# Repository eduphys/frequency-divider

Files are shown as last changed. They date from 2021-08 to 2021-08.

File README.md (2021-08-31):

# README

This repository contains the schematics and firmware for a frequency divider used in an experiment for time resolved transmission electron microscopy.
The frequency divider can operate up to 4 GHz and is optimized for low timing jitter. The jitter has not been determined by measurements, but calculations using the jiter of the individual components of the signal path lead to <5ps. The input is designed for 90-200mV pp.

The divider can be configured for a division factor of (2^a)(2^b) with a=0...3 and b=0...5.

## CAUTION:
The NB6N239S chip is not manufactured anymore. It is highly recommended to re-design the board!

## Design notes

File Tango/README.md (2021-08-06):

# README

This Tango server connectos th the Frequency divider.
The frequency divider is connected via an USB cable to the computer.
The software on the divider recieves the divider setting over the serial protocol

## Setup

### Permission
In order to be able to connect to the serial port, the linux user needs the permissions

  sudo usermod -a -G dialout $USER

Log out and log in again

Find the serial port, best with 

  dmesg | grep tty

### Packages

The python programm nees the pyserial libraries

## Debug

## Serial GUI
To debug the serial connection, one can use the programm cutecom.

## Permission denied
You could try

   sudo chmod 666 /dev/ttyACM0

Which will give you read/write permissions for the serial port (thanks to https://discourse.nodered.org/t/serial-port-issue-permission-denied-cannot-open-dev-ttyacm0/4500/2)

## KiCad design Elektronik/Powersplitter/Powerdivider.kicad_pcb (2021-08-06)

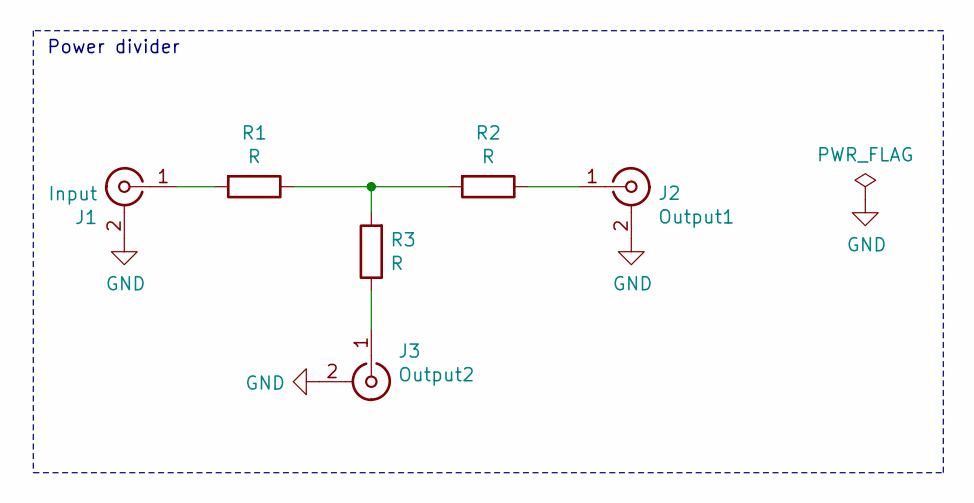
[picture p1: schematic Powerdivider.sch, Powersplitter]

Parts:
J1: Input; SMA_Amphenol_132289_EdgeMount
J2: Output1; SMA_Amphenol_132289_EdgeMount
J3: Output2; SMA_Amphenol_132289_EdgeMount
R1, R2, R3: R; R_0603_1608Metric_Pad1.05x0.95mm_HandSolder

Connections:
GND: J1.2 (Ext), J2.2 (Ext), J3.2 (Ext)
unnamed: J1.1 (In), R1.2
unnamed: J2.1 (In), R2.1
unnamed: J3.1 (In), R3.1
unnamed: R1.1, R2.2, R3.2

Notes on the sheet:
Power divider

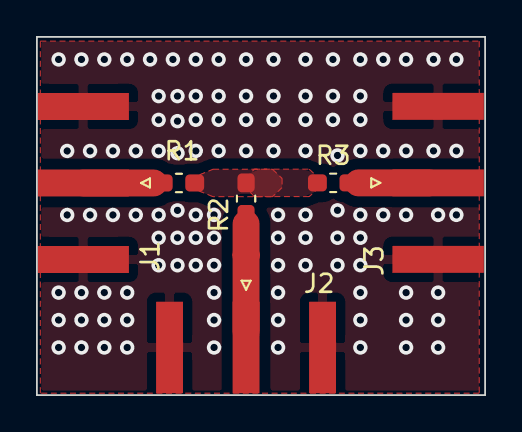
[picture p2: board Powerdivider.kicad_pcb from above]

Board: 2 copper layers, 24.9 x 19.9 mm, 6 parts (0 on the bottom side), 5 nets.

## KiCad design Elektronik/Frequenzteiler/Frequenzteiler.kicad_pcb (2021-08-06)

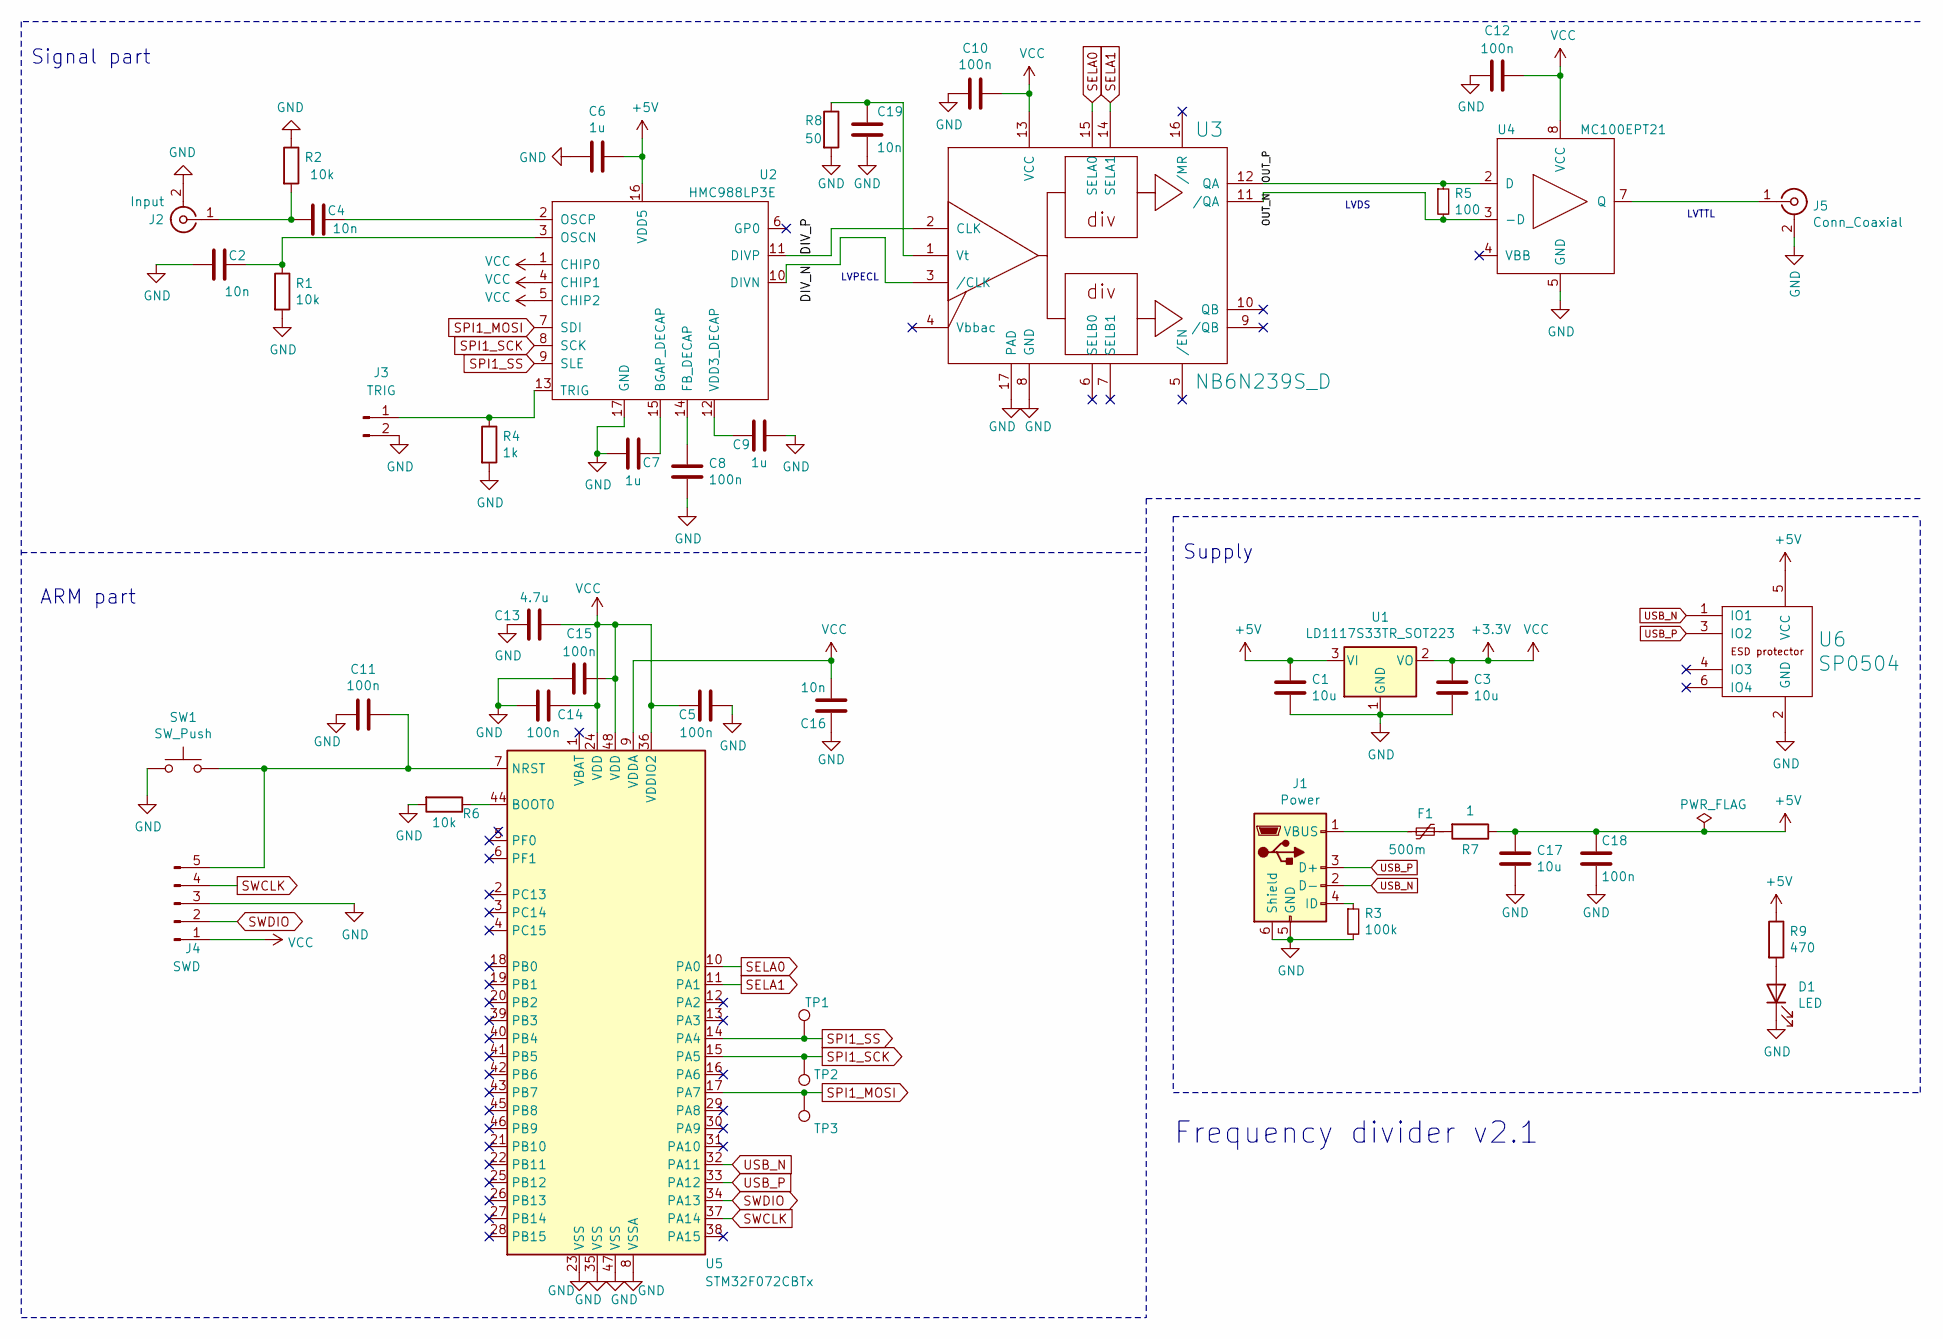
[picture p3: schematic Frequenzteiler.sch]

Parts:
C1, C3, C17: 10u; C_1206_3216Metric_Pad1.42x1.75mm_HandSolder
C2, C4, C16, C19: 10n; C_0603_1608Metric_Pad1.05x0.95mm_HandSolder
C5, C8, C10, C11, C12, C14, C15, C18: 100n; C_0603_1608Metric_Pad1.05x0.95mm_HandSolder
C6, C7, C9: 1u; C_0603_1608Metric_Pad1.05x0.95mm_HandSolder
C13: 4.7u; C_0805_2012Metric_Pad1.15x1.40mm_HandSolder
D1: LED; LED_0805_2012Metric_Pad1.15x1.40mm_HandSolder
F1: 500m; R_1206_3216Metric_Pad1.42x1.75mm_HandSolder
J1: Power; USB_Mini-B_Lumberg_2486_01_Horizontal
J2: Input; SMA_Amphenol_132289_EdgeMount
J3: TRIG; PinHeader_1x02_P2.54mm_Vertical
J4: SWD; PinHeader_1x05_P2.54mm_Vertical
J5: Conn_Coaxial; SMA_Amphenol_132289_EdgeMount
R1, R2, R6: 10k; R_0603_1608Metric_Pad1.05x0.95mm_HandSolder
R3: 100k; R_0603_1608Metric_Pad1.05x0.95mm_HandSolder
R4: 1k; R_0603_1608Metric_Pad1.05x0.95mm_HandSolder
R5: 100; R_0603_1608Metric_Pad1.05x0.95mm_HandSolder
R7: 1; R_0603_1608Metric_Pad1.05x0.95mm_HandSolder
R8: 50; R_0603_1608Metric_Pad1.05x0.95mm_HandSolder
R9: 470; R_0603_1608Metric_Pad1.05x0.95mm_HandSolder
SW1: SW_Push; SW_SPST_B3U-1000P
TP1, TP2, TP3: TestPoint; TestPoint_THTPad_D1.0mm_Drill0.5mm
U1: LD1117S33TR_SOT223; SOT-223-3_TabPin2
U2: HMC988LP3E; LFCSP-16-1EP_3x3mm_P0.5mm_EP1.854x1.854mm
U3: NB6N239S_D; LFCSP-16-1EP_3x3mm_P0.5mm_EP1.854x1.854mm
U4: MC100EPT21; TSSOP-8_3x3mm_P0.65mm
U5: STM32F072CBTx; LQFP-48_7x7mm_P0.5mm
U6: SP0504; SOT-23-6_Handsoldering

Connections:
+3V3: C3.1, C5.2, C10.1, C12.2, C13.1, C14.1, C15.1, C16.2, J4.1, U1.2 (VO), U2.1 (CHIP0), U2.4 (CHIP1), U2.5 (CHIP2), U3.13 (VCC), U4.8 (VCC), U5.9 (VDDA), U5.24 (VDD), U5.36 (VDDIO2), U5.48 (VDD)
+5V: C1.1, C6.1, C17.1, C18.1, R7.1, R9.1, U1.3 (VI), U2.16 (VDD5), U6.5 (VCC)
/DIV_N: U2.10 (DIVN), U3.3 (/CLK)
/DIV_P: U2.11 (DIVP), U3.2 (CLK)
/OUT_N: R5.2, U3.11 (/QA), U4.3 (-D)
/OUT_P: R5.1, U3.12 (QA), U4.2 (D)
GND: C1.2, C2.1, C3.2, C5.1, C6.2, C7.2, C8.2, C9.1, C10.2, C11.1, C12.1, C13.2, C14.2, C15.2, C16.1, C17.2, C18.2, C19.2, D1.1 (K), J1.5 (GND), J1.6 (Shield), J2.2 (Ext), J3.2, J4.3, J5.2 (Ext), R1.2, R2.1, R3.2, R4.2, R6.2, R8.2, SW1.1, U1.1 (GND), U2.17 (GND), U3.8 (GND), U3.17 (PAD), U4.5 (GND), U5.8 (VSSA), U5.23 (VSS), U5.35 (VSS), U5.47 (VSS), U6.2 (GND)
unnamed: C2.2, R1.1, U2.3 (OSCN)
unnamed: C4.1, U2.2 (OSCP)
unnamed: C4.2, J2.1 (In), R2.2
unnamed: C7.1, U2.15 (BGAP_DECAP)
unnamed: C8.1, U2.14 (FB_DECAP)
unnamed: C9.2, U2.12 (VDD3_DECAP)
unnamed: C11.2, J4.5, SW1.2, U5.7 (NRST)
unnamed: C19.1, R8.1, U3.1 (Vt)
unnamed: D1.2 (A), R9.2
unnamed: F1.1, R7.2
unnamed: F1.2, J1.1 (VBUS)
unnamed: J1.4 (ID), R3.1
unnamed: J3.1, R4.1, U2.13 (TRIG)
unnamed: J5.1 (In), U4.7 (Q)
unnamed: R6.1, U5.44 (BOOT0)
SELA0: U3.15 (SELA0), U5.10 (PA0)
SELA1: U3.14 (SELA1), U5.11 (PA1)
SPI1_MOSI: TP3.1, U2.7 (SDI), U5.17 (PA7)
SPI1_SCK: TP2.1, U2.8 (SCK), U5.15 (PA5)
SPI1_SS: TP1.1, U2.9 (SLE), U5.14 (PA4)
SWCLK: J4.4, U5.37 (PA14)
SWDIO: J4.2, U5.34 (PA13)
USB_N: J1.2 (D-), U5.32 (PA11), U6.1 (IO1)
USB_P: J1.3 (D+), U5.33 (PA12), U6.3 (IO2)

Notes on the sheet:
ARM part
Frequency divider v2.1
Signal part
Supply
LVPECL
LVDS
LVTTL

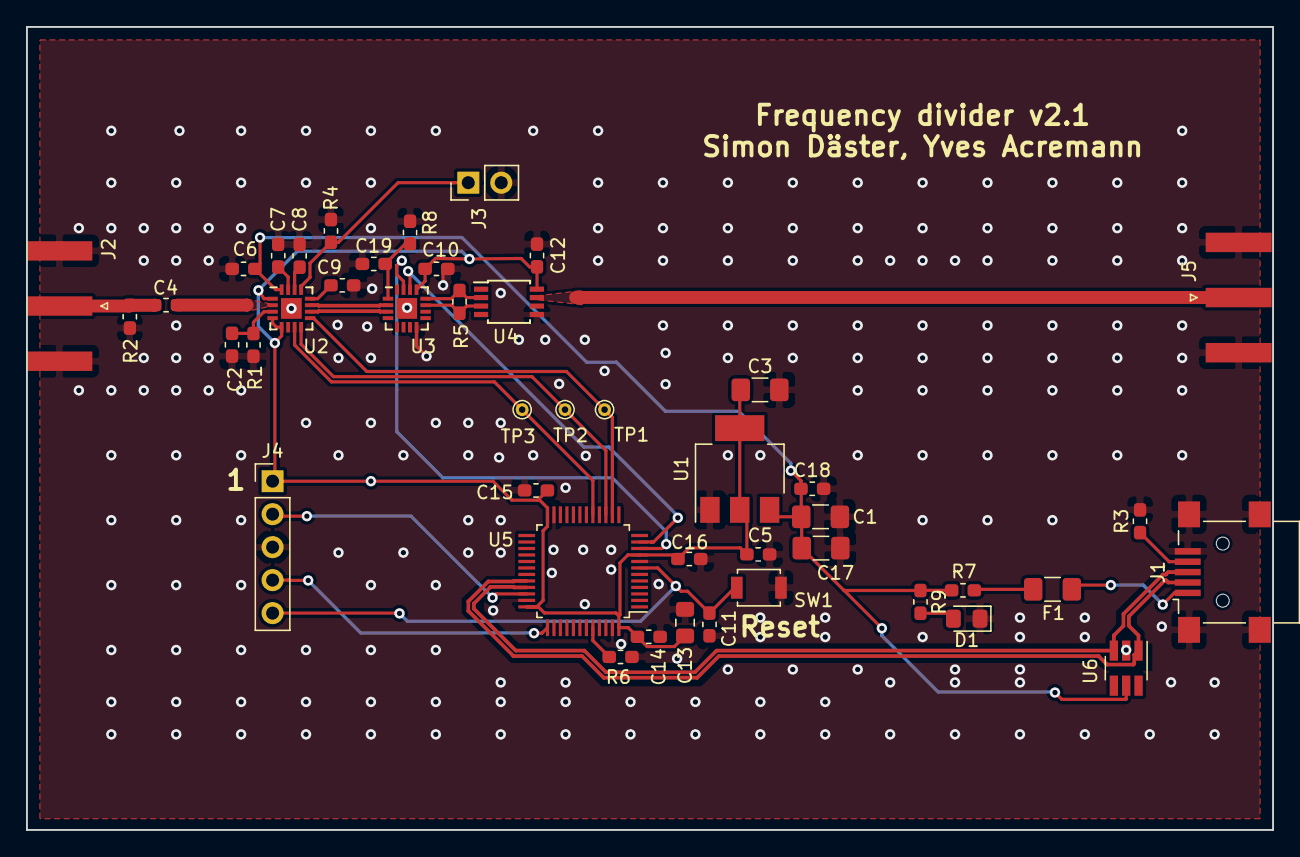
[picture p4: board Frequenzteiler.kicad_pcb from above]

Board: 2 copper layers, 96.0 x 61.9 mm, 45 parts (0 on the bottom side), 31 nets.

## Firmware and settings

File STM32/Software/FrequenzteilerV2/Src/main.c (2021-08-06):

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
/* Includes ------------------------------------------------------------------*/
#include "main.h"
#include "usb_device.h"

/* USER CODE BEGIN Includes */

#include "usbd_cdc_if.h"
#include "HMCWriter.h"
#include "SerialCommunication.h"

/* USER CODE END Includes */

/* USER CODE BEGIN PD */

int delay = 100;

//initial set
unsigned int divider = 32;

/* USER CODE END PD */

SPI_HandleTypeDef hspi1;

void SystemClock_Config(void);
static void MX_GPIO_Init(void);
static void MX_SPI1_Init(void);
/* USER CODE BEGIN PFP */
void send_message(char text[]);
void process_buffer();
unsigned int set_divider(unsigned int divider);
/* USER CODE END PFP */

/**
  * @brief  The application entry point.
  * @retval int
  */
int main(void)
{
  /* MCU Configuration--------------------------------------------------------*/

  /* Reset of all peripherals, Initializes the Flash interface and the Systick. */
  HAL_Init();

  /* Configure the system clock */
  SystemClock_Config();

  /* Initialize all configured peripherals */
  MX_GPIO_Init();
  MX_SPI1_Init();
  MX_USB_DEVICE_Init();
  /* USER CODE BEGIN 2 */

  /*
   * Set divider of the NB6N239S chip. Divider can be 1,2,4,8
   * See the following table to set
   * SELA1 SELA0  	QA Outputs
	 L		L		Divide by 1
	 L		H		Divide by 2
	 H		L		Divide by 4
	 H		H		Divide by 8

	 High (H) is GPIO_PIN_SET, Low (L) is GPIO_PIN_RESET
   */
  HAL_GPIO_WritePin(SELA1_GPIO_Port, SELA1_Pin, GPIO_PIN_RESET);
  HAL_GPIO_WritePin(SELA0_GPIO_Port, SELA0_Pin, GPIO_PIN_RESET);


  // set GPO of HMC to 1
  writeHMCReg(0x05,0x01);

  // what does that?
  writeHMCReg(0x04,0x08);

  // divider settings
  // 0: /1
  //1: /2
  //2: /4
  //3: /8
  //4: /16
  //5: /32
  //6: N/A
  //7: N/A
  writeHMCReg(0x02,0x05);

  // sleep
  // maybe best to use Stop mode instead of Standby mode. See STM32F072x8/xB manual, page 15
  //HAL_PWR_EnterStopMode();

  send_message("...Initialization complete\n");
  /* USER CODE END 2 */

  /* Infinite loop */
  /* USER CODE BEGIN WHILE */
  while (1)
  {
    /* USER CODE END WHILE */

    /* USER CODE BEGIN 3 */
	if (SerialComm_EndReached()) {
		//debug
		//send_message("Cmd received\n");

		process_buffer();

		// restart buffering
		SerialComm_StartBuffering();

	}



	// send "Hello World every 5000 milliseconds
//	if (5000 - counter*delay < delay) {
//		send_message("I'm alive\n");
//		counter = 0;
//	} else {
//		++counter;
//	}

	HAL_Delay(delay);
  }
  /* USER CODE END 3 */
}

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
/* USER CODE BEGIN 4 */
void send_message(char text[])
{
	uint16_t len = strlen((char *)text);
	CDC_Transmit_FS((uint8_t*)text, len);
	HAL_Delay(delay);
}


// where the magic happens
void process_buffer()
{
	// process the buffer. This function is called  in main loop
	// when the buffering stopped, i.e. endline received
	// then this function process the buffer and
	// implements the protocoll
	//
	//pointer to cmd buffer
	uint8_t * buffer;
	buffer = SerialComm_Cmd_Buffer();
	// length
	uint32_t len = 0;
	len = SerialComm_Cmd_Buffer_Len();

	char text[12];

	unsigned int new_divider;

	for (int i = 0; i < len; ++i) {

		switch (buffer[i]) {
		case 'd':

			sprintf(text, "%u\n", divider);
			send_message(text);

			return;

		case 'D':
//			send_message("Set divider cmd found\n");

			//read out buffer
			//first byte is 'D', so ignore
			sscanf(&buffer[1],"%u\n",&new_divider);

			//debug
//			CDC_Transmit_FS(buffer, len);
//			HAL_Delay(delay);


			if (!set_divider(new_divider)) {
				sprintf(text, "%u\n", new_divider);
				send_message(text);
			}
			return;
		}

	}


}


unsigned int set_divider(unsigned int new_divider)
{
//	uint8_t text[36];
//	sprintf(text, "new Divider %d\n", new_divider);
//	send_message(text);
//	return;

	if ((new_divider%2 != 0 && new_divider != 1) || new_divider > 32 || new_divider < 1)
	{
		char text[36];
		sprintf(text, "Divider %d invalid\n", new_divider);
		send_message(text);
		return 1;
	}


	//make log 2 of divider
	unsigned int HMC_divider_set = 0;
	unsigned int temp = new_divider;
	unsigned int divider2store = 1;

	// make shifts (log2 and power 2)
	while (temp >>= 1) {
		HMC_divider_set++;
		divider2store <<= 1;
	}

	// check log 2
	if (divider2store != new_divider) {
		char text[36];
		sprintf(text, "Divider %d invalid, not equal %d\n", new_divider, divider2store);
		send_message(text);
		return 1;
	}

	// set global divider information
	divider = new_divider;


	// divider settings
	// 0: /1
	//1: /2
	//2: /4
	//3: /8
	//4: /16
	//5: /32
	//6: N/A
	//7: N/A
	writeHMCReg(0x02,HMC_divider_set);

	return 0;

}
/* USER CODE END 4 */
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


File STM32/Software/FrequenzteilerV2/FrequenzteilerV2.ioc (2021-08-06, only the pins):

Mcu.UserName=STM32F072CBTx
PA0.Signal=GPIO_Output
PA1.Signal=GPIO_Output
PA11.Signal=USB_DM
PA12.Signal=USB_DP
PA13.Signal=SYS_SWDIO
PA14.Signal=SYS_SWCLK
PA4.Signal=SPI1_NSS
PA5.Signal=SPI1_SCK
PA7.Signal=SPI1_MOSI

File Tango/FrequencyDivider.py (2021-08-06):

# -*- coding: utf-8 -*-
#
# This file is part of the FrequencyDivider project
#
# GPL
#
# Distributed under the terms of the GPL license.
# See LICENSE.txt for more info.

""" FrequencyDivider

TangoServer to access the frequency divider and change the divider setting.
"""

# PyTango imports
import tango
from tango import DebugIt
from tango.server import run
from tango.server import Device, DeviceMeta
from tango.server import attribute, command
from tango.server import device_property
from tango import AttrQuality, DispLevel, DevState
from tango import AttrWriteType, PipeWriteType
# Additional import
# PROTECTED REGION ID(FrequencyDivider.additionnal_import) ENABLED START #
from SerialCom import SerialCom
# PROTECTED REGION END #    //  FrequencyDivider.additionnal_import

__all__ = ["FrequencyDivider", "main"]


class FrequencyDivider(Device):
    """
    TangoServer to access the frequency divider and change the divider setting.

    **Properties:**

    - Device Property
        port
            - Type:'DevString'
    """
    __metaclass__ = DeviceMeta
    # PROTECTED REGION ID(FrequencyDivider.class_variable) ENABLED START #
    # PROTECTED REGION END #    //  FrequencyDivider.class_variable

    # -----------------
    # Device Properties
    # -----------------

    port = device_property(
        dtype='DevString',
        mandatory=True
    )

    # ----------
    # Attributes
    # ----------

    Divider = attribute(
        dtype='DevShort',
        access=AttrWriteType.READ_WRITE,
        memorized=True,
    )

    # ---------------
    # General methods
    # ---------------

    def init_device(self):
        """Initialises the attributes and properties of the FrequencyDivider."""
        Device.init_device(self)
        # PROTECTED REGION ID(FrequencyDivider.init_device) ENABLED START #
        self.set_state(tango.DevState.STANDBY)
        self.com = SerialCom(self.port)
        
        try:
            self.com.open()
            self.com.read_divider()
        except tango.DevFailed:
            self.set_status('Serial port could not be opened')
            self.set_state(tango.DevState.FAULT)
            
        
        
       
        # PROTECTED REGION END #    //  FrequencyDivider.init_device

    def always_executed_hook(self):
        """Method always executed before any TANGO command is executed."""
        # PROTECTED REGION ID(FrequencyDivider.always_executed_hook) ENABLED START #
        if self.com.is_open():
            self.set_state(tango.DevState.ON)
        else:
            self.set_state(tango.DevState.STANDBY)
        # PROTECTED REGION END #    //  FrequencyDivider.always_executed_hook

    def delete_device(self):
        """Hook to delete resources allocated in init_device.

        This method allows for any memory or other resources allocated in the
        init_device method to be released.  This method is called by the device
        destructor and by the device Init command.
        """
        # PROTECTED REGION ID(FrequencyDivider.delete_device) ENABLED START #
        self.com.close()
        # PROTECTED REGION END #    //  FrequencyDivider.delete_device
    # ------------------
    # Attributes methods
    # ------------------

    def read_Divider(self):
        # PROTECTED REGION ID(FrequencyDivider.Divider_read) ENABLED START #
        """Return the Divider attribute."""
        
        return self.com.divider
        
        # PROTECTED REGION END #    //  FrequencyDivider.Divider_read

    def write_Divider(self, value):
        # PROTECTED REGION ID(FrequencyDivider.Divider_write) ENABLED START #
        """Set the Divider attribute."""
        if value < 1 or value > 32 or (value%2 != 0 and value != 1):
            self.set_status("Divider not valid")
            return
        
        self.com.set_divider(value)
        # PROTECTED REGION END #    //  FrequencyDivider.Divider_write

    def is_Divider_allowed(self, attr):
        # PROTECTED REGION ID(FrequencyDivider.is_Divider_allowed) ENABLED START #
        if attr==attr.READ_REQ:
            return self.get_state() not in [DevState.STANDBY]
        else:
            return self.get_state() not in [DevState.STANDBY]
        # PROTECTED REGION END #    //  FrequencyDivider.is_Divider_allowed

    # --------
    # Commands
    # --------

    @command(
    )
    @DebugIt()
    def Open(self):
        # PROTECTED REGION ID(FrequencyDivider.Open) ENABLED START #
        """
        Open port

        :return:None
        """
        self.com.open()
        # PROTECTED REGION END #    //  FrequencyDivider.Open

    @command(
    )
    @DebugIt()
    def Close(self):
        # PROTECTED REGION ID(FrequencyDivider.Close) ENABLED START #
        """
        Close port

        :return:None
        """
        self.com.close()
        # PROTECTED REGION END #    //  FrequencyDivider.Close

# ----------
# Run server
# ----------


def main(args=None, **kwargs):
    """Main function of the FrequencyDivider module."""
    # PROTECTED REGION ID(FrequencyDivider.main) ENABLED START #
    return run((FrequencyDivider,), args=args, **kwargs)
    # PROTECTED REGION END #    //  FrequencyDivider.main


if __name__ == '__main__':
    main()

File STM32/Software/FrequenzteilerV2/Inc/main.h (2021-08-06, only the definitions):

#define SELA0_Pin GPIO_PIN_2
#define SELA0_GPIO_Port GPIOA
#define SELA1_Pin GPIO_PIN_3
#define SELA1_GPIO_Port GPIOA
#define DIVIDER_INIT 4;

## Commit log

2021-08-06 Added Electronics
    [Frequenzteiler.kicad_pcb, Frequenzteiler.sch, Powerdivider.kicad_pcb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]
2021-08-06 Added STM32 project files and code

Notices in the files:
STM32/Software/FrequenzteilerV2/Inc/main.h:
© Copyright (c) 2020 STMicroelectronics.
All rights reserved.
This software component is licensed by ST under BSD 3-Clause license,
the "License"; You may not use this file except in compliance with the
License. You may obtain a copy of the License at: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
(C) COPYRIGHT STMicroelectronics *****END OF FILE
